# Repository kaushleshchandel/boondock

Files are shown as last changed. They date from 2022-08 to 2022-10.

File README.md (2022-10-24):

## Boondock Echo
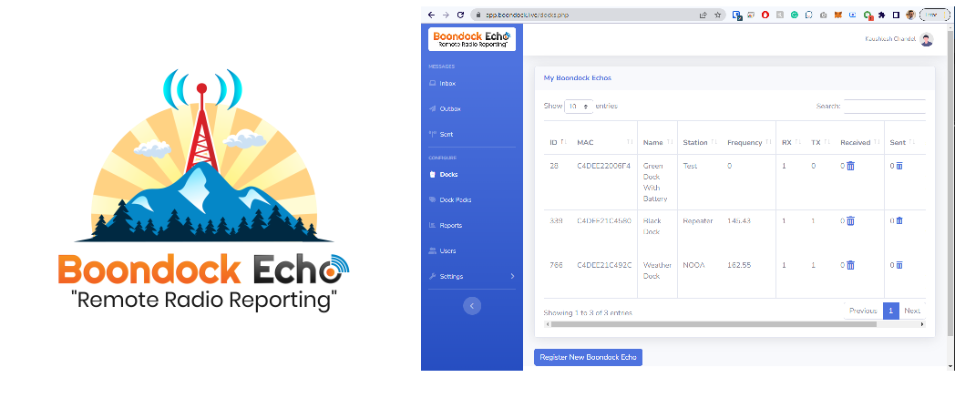
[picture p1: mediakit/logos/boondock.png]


### What is Boondock Echo?
Boondock Echo is a time-shift audio project created for emergency radio communications. A Boondock Echo module connects to transceivers with audio cables between the mic and speaker of the radio and the speaker and mic of the Bookdock Echo moule. 

The Boondock Echo listens to the radio for traffic. Whenever new traffic is received, it captures the audio as a .wav on a local sd card, and then sends the file to sever for storage, and queing, and playback. Users can play back messages on the Boondock browser interface or que messages for transmission on a radio.

Having the audio files on the cloud, enables us to have some really cool features to a radio, that were not possible earlier. like, converting audio to text, using text to speech, audio noice reduction, and pre-porcessing audio.

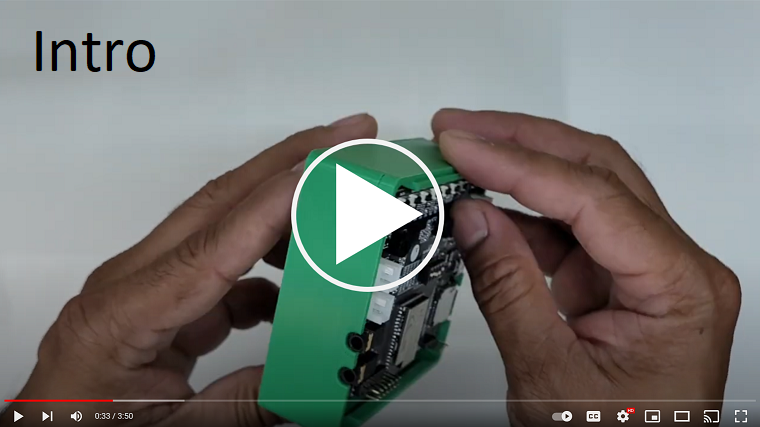
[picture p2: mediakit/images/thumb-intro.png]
Watch the video (https://youtu.be/K9tplKsggrA)
 

### How to get started with Boondock
All the source code you would need is included in this repositories. You will also need to create google cloud account for Text to Speech & Speech to Text features. The build instructions are split into four steps. Each part has a linked instructional video.

<ol>
  <li>Assembling the hardware</li>
  <li>Setting up the Web Server</li>
  <li>Programming the Boondock</li>
  <li>Getting Started</li>
</ol>

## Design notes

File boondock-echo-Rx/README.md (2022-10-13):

### STEP 3. Programming the Boondock

After assembling your boondock echo, you need a micro USB cable to program your boondock Echo. [CLICK HERE](/3d.print/README.md) for Assembly instructions and video.

#### Prepare the SD Card
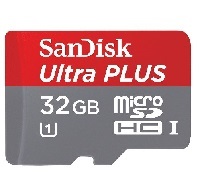
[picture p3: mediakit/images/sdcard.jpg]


You can use any size SD card and format it to FAT32. I have used a 32GB micro SD card, so I would recommend using the same.

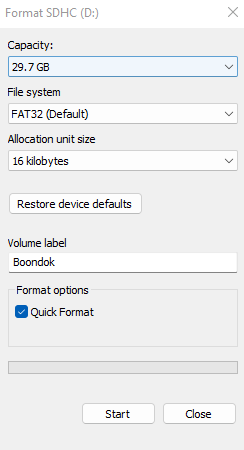
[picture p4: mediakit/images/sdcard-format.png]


After formatting the card, copy all the files from the folder named **sd_card**

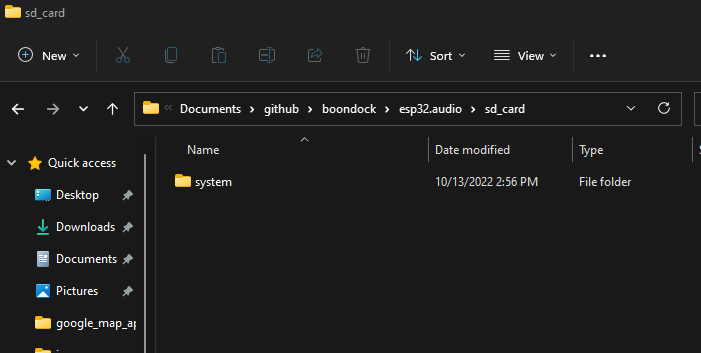
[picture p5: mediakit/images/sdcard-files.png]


The system folder has some files that are used by boondock Echo. After the boondock starts for the first time, it will create some folders. All the audio files are stored on the SD card.

#### Prepare the IDE to program Boondock Echo.

You can watch the detailed video on setting up Platform IO and Visual Studio code. If you are familiar with visual studio code, open the folder with ESP32 audio code.
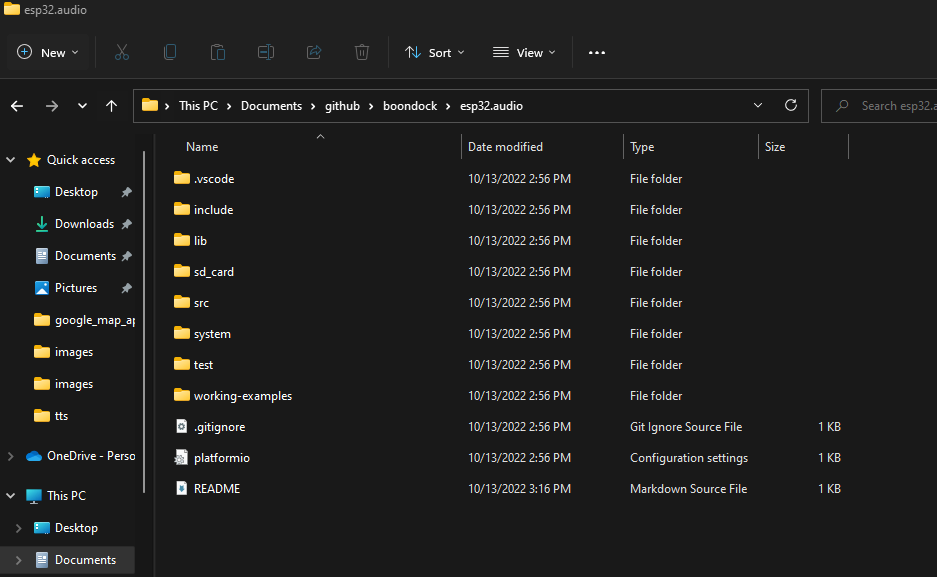
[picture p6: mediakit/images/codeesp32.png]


Before you upload the code, you need to setup some configurations.

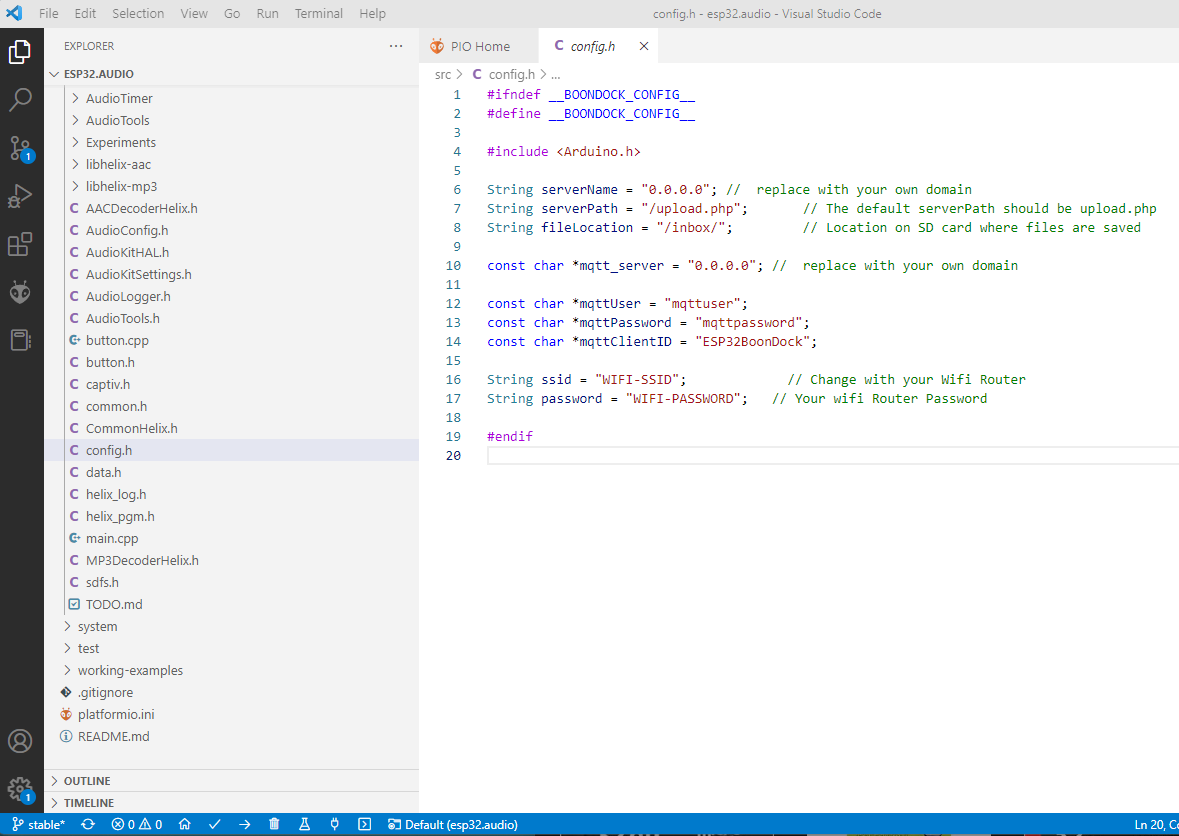
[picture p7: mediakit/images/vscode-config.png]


Now connect the Boondock Echo using a Micro USB cable, and click upload.
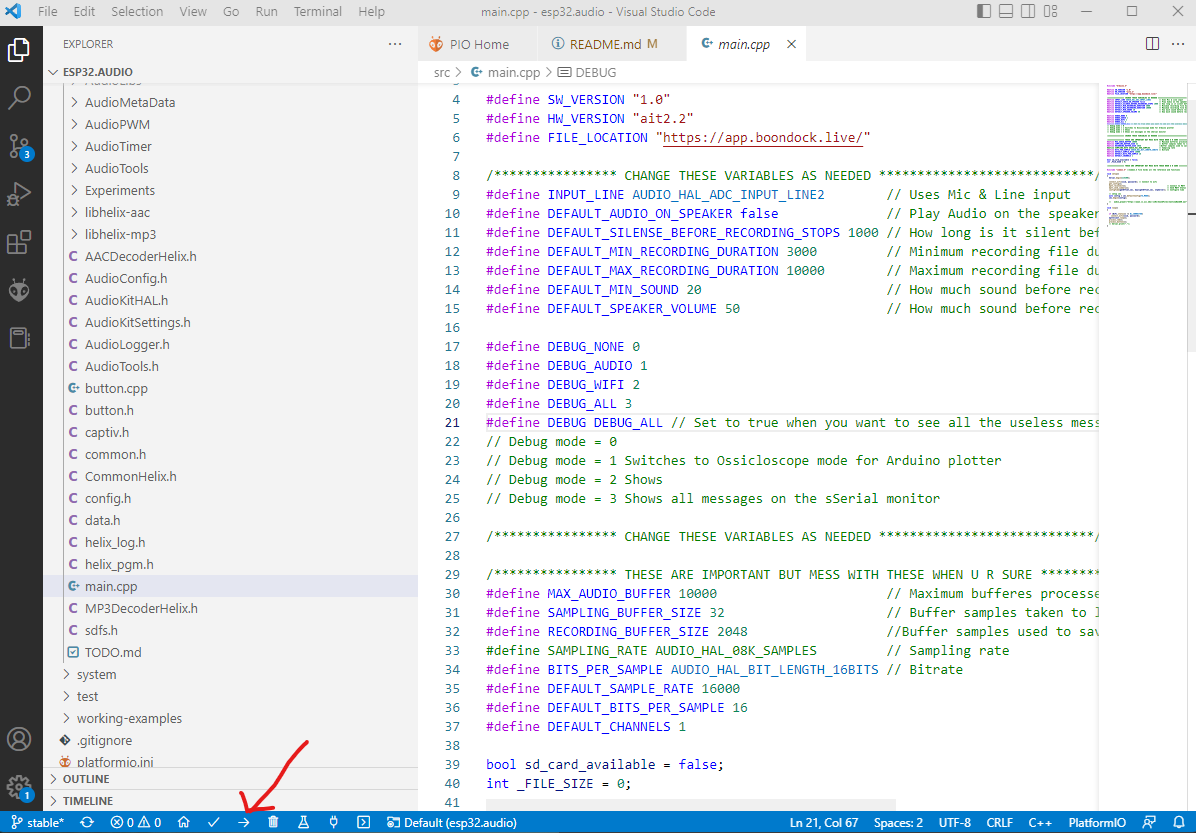
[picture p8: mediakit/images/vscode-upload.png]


Now your boondock echo is all set and ready for use.

**Cheers!**

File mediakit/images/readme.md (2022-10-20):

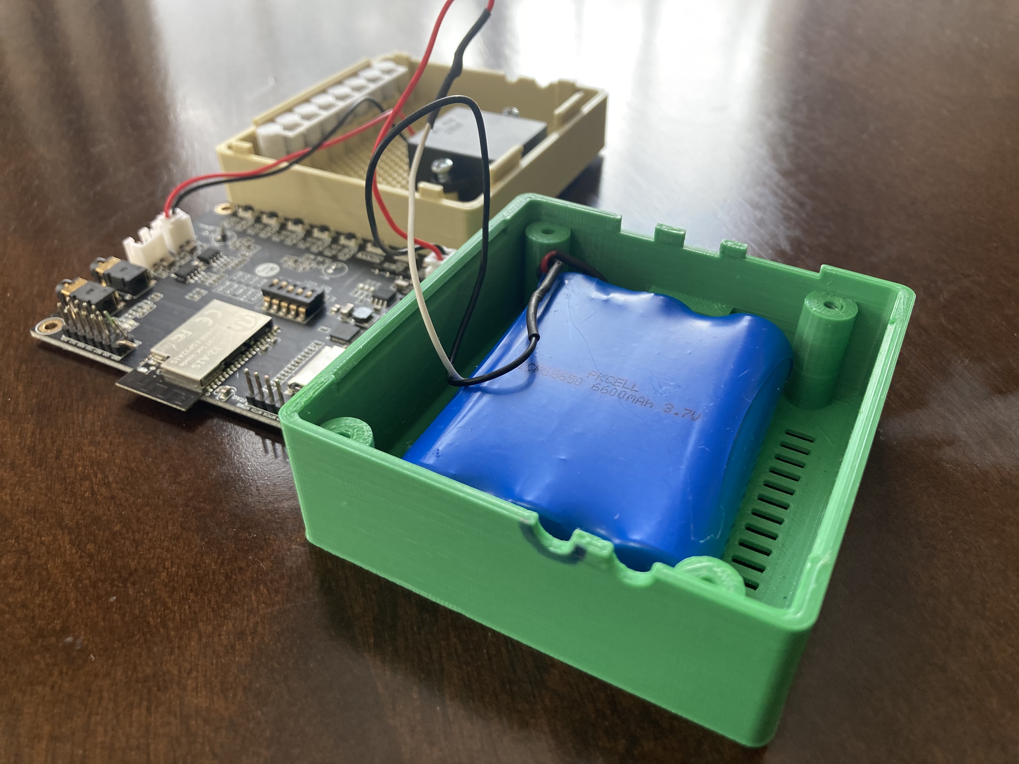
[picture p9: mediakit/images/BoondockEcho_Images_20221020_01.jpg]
Boondock Echo Open Case

 
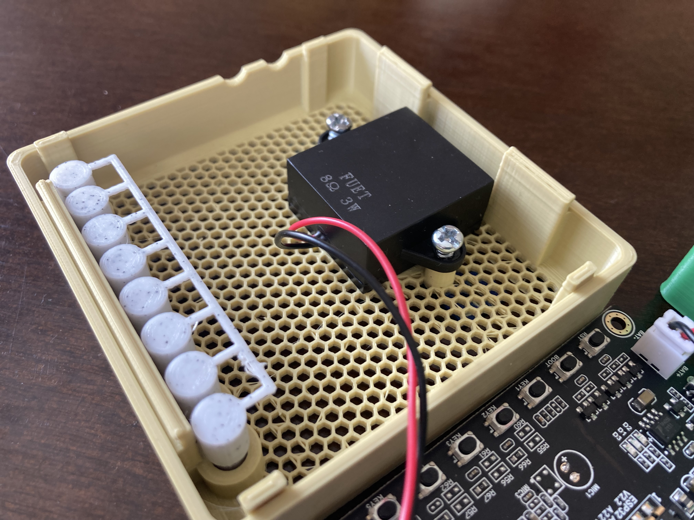
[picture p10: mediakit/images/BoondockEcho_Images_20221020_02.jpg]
Boondock Echo Top Case

 
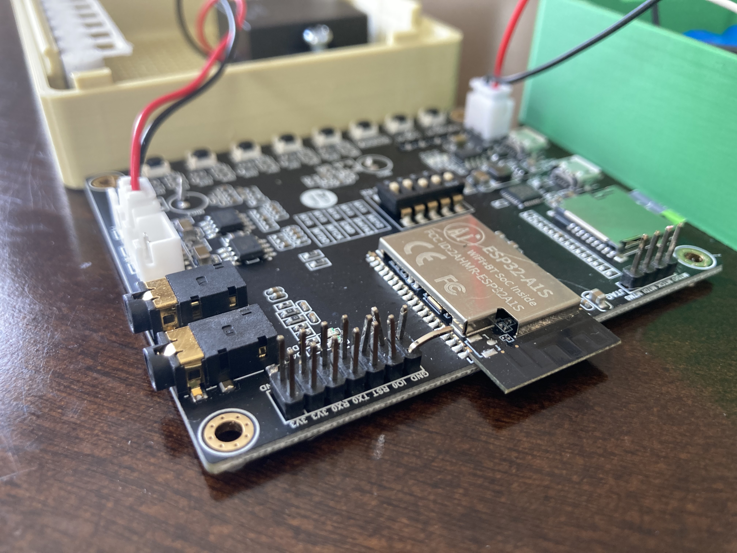
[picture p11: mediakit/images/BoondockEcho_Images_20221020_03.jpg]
Boondock Echo ESP Audio Kit

 
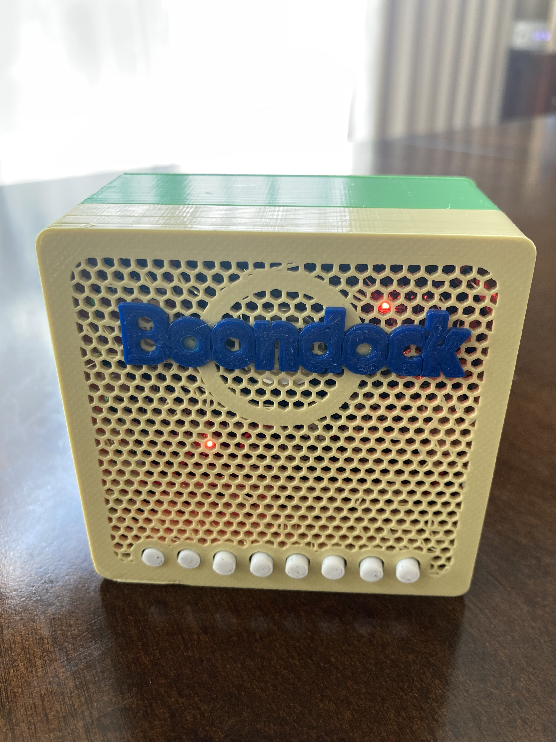
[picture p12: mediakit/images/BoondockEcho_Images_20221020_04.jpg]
Boondock Echo New Top Case Design

 
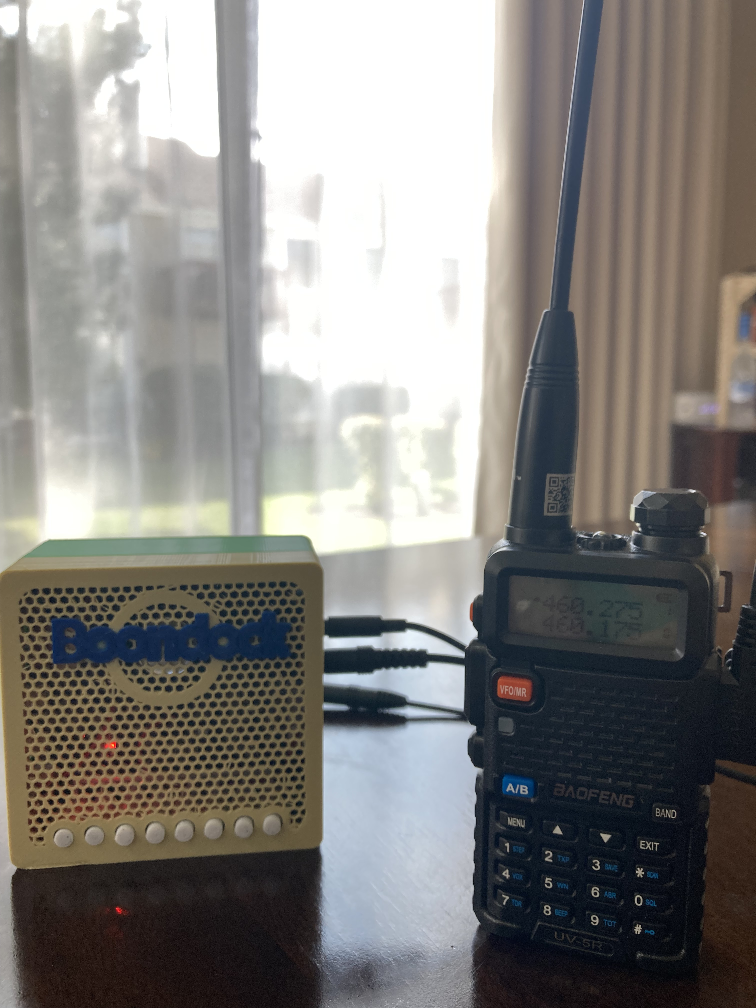
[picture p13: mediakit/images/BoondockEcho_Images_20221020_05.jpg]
Boondock Echo With Radio

 
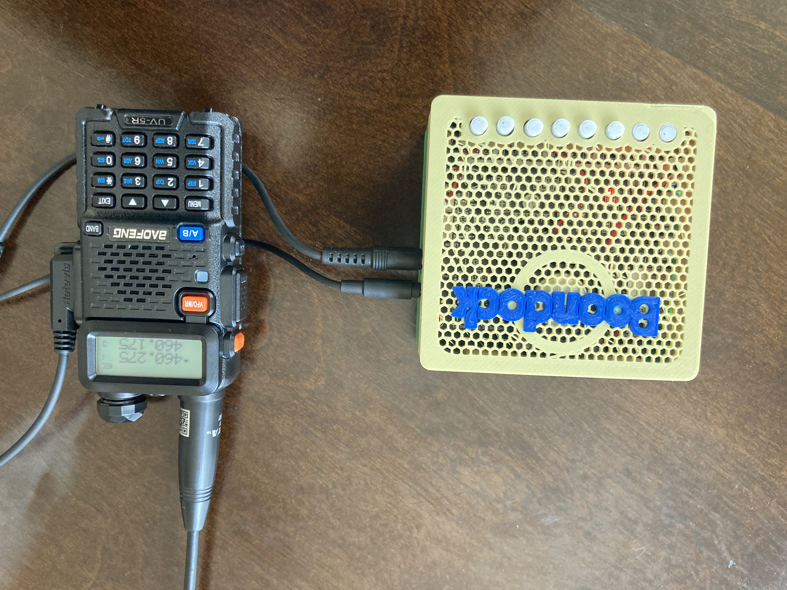
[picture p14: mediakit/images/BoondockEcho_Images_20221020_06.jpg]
Boondock Echo With Radio

 
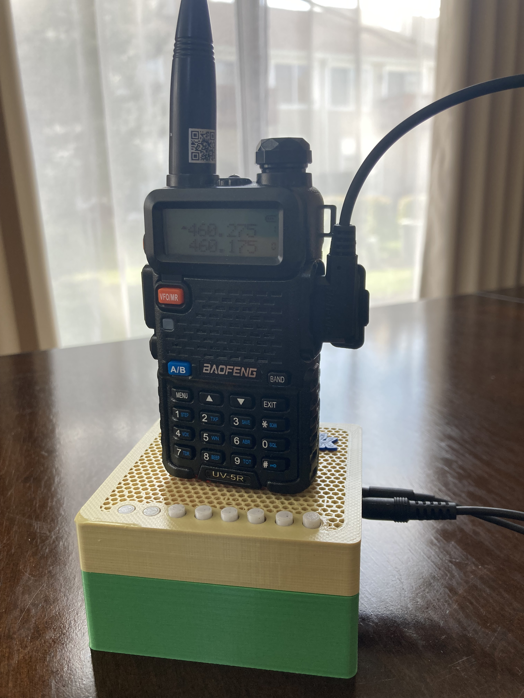
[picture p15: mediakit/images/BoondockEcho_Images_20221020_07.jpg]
Boondock Echo Under Radio

 
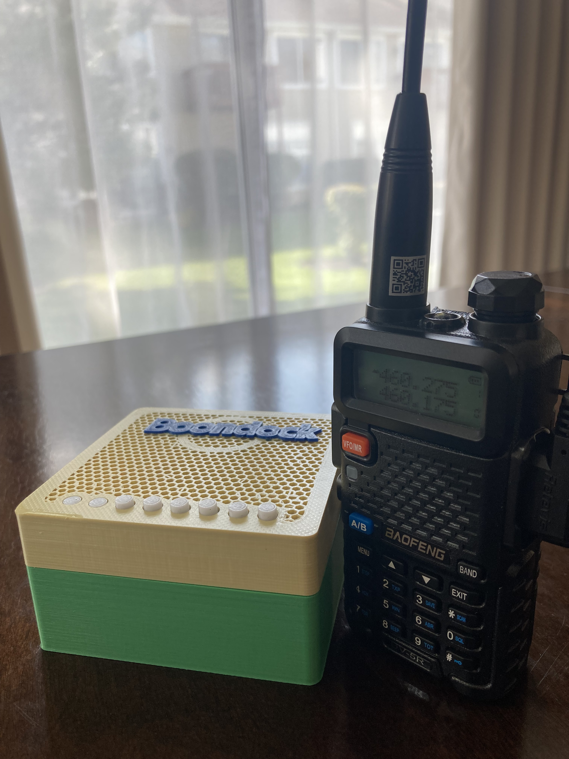
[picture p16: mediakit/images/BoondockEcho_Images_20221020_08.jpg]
Boondock Echo Next to Radio


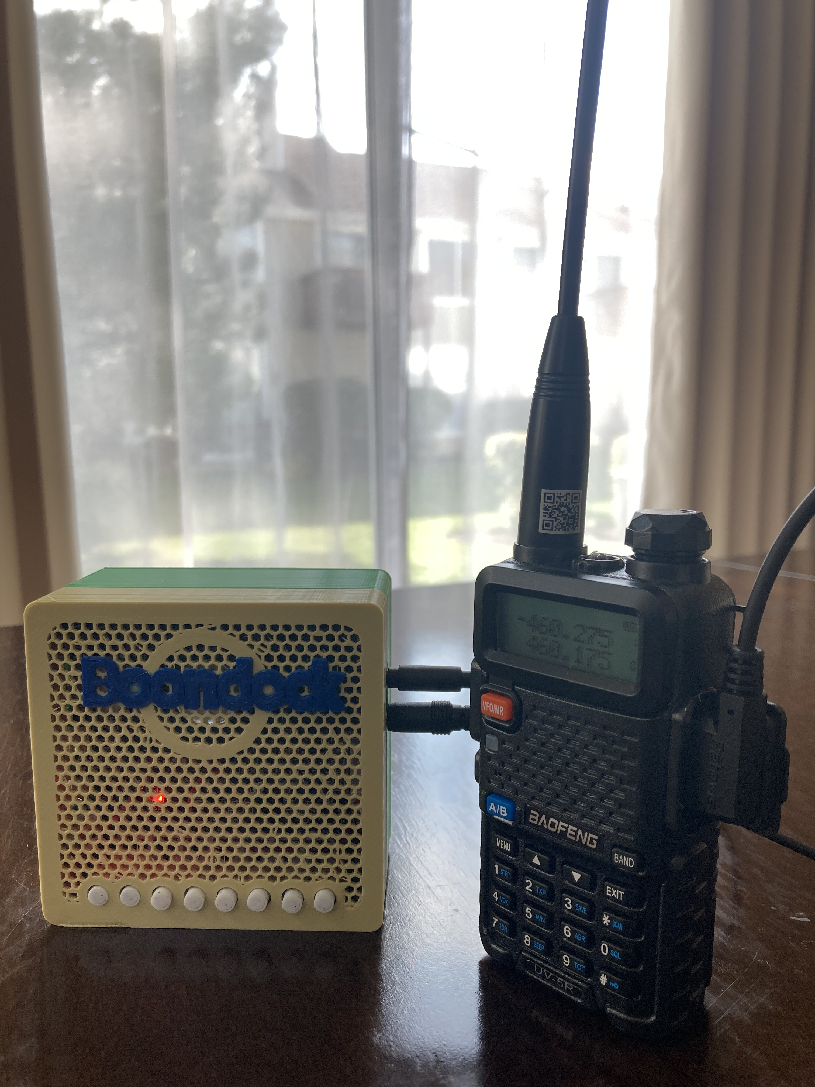
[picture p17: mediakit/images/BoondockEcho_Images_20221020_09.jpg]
Boondock Echo Next to Radio


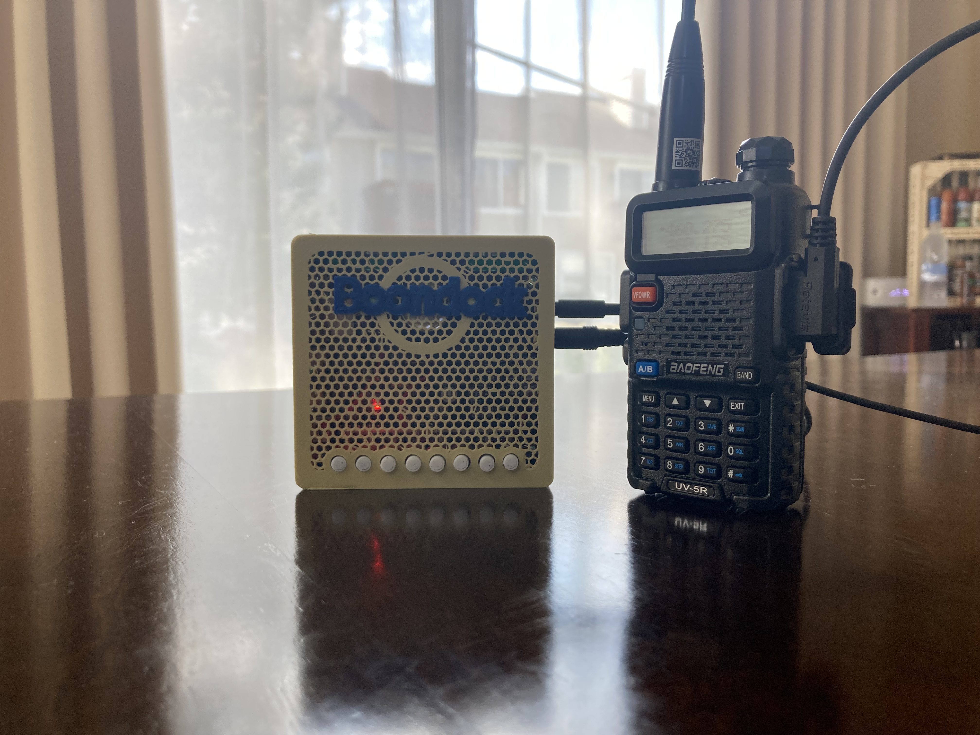
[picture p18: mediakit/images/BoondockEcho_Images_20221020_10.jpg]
Boondock Echo Next to Radio


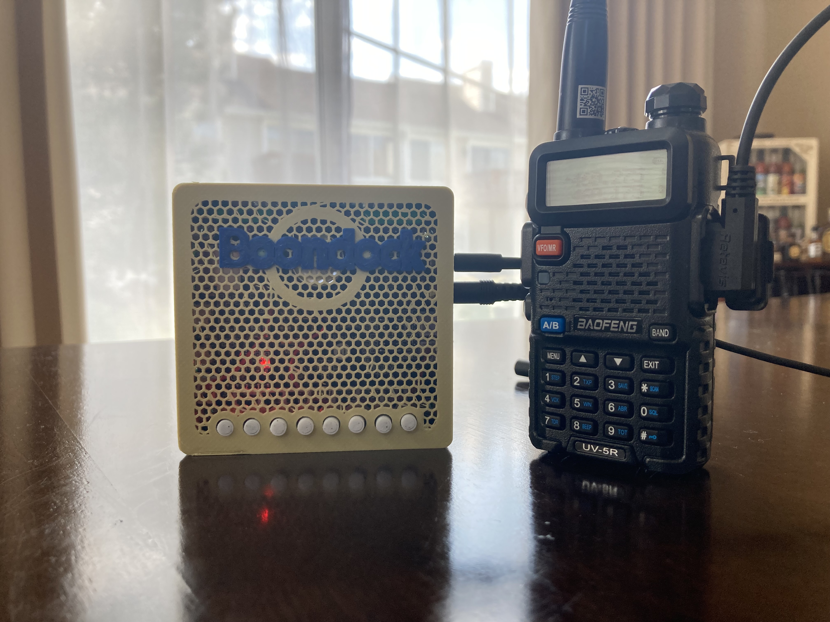
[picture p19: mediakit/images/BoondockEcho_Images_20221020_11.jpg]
Boondock Echo Next to Radio


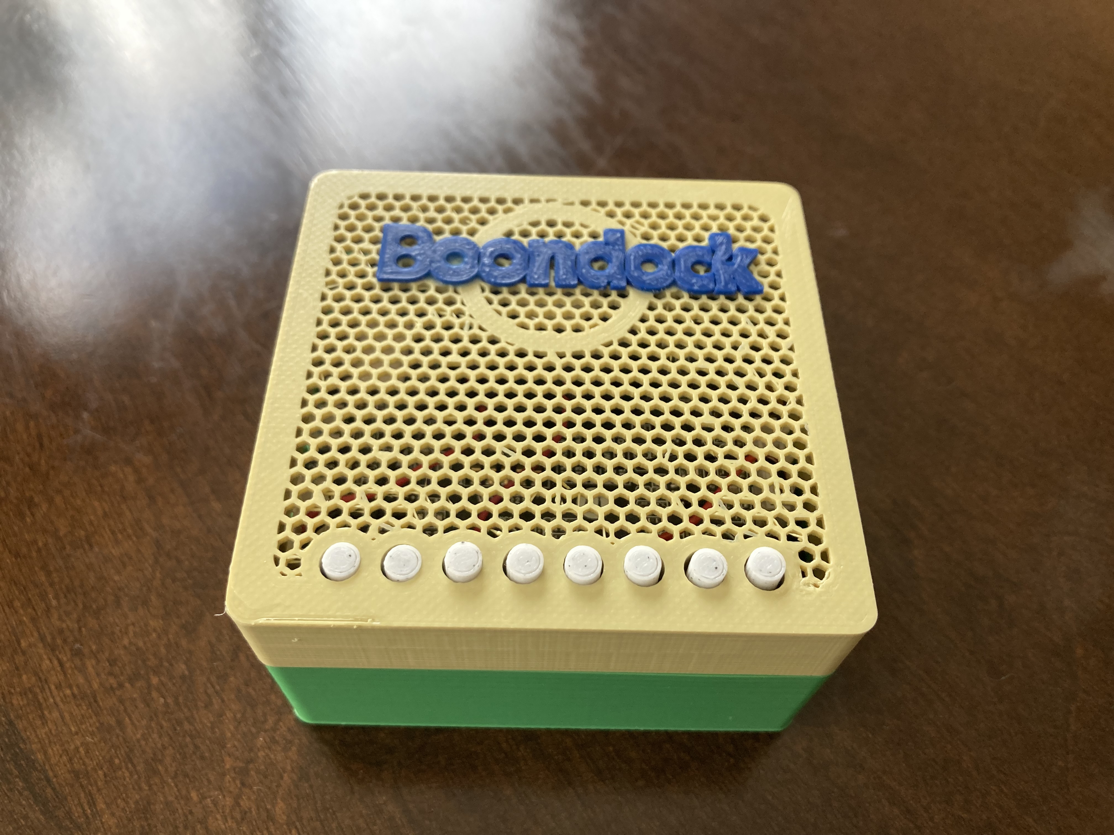
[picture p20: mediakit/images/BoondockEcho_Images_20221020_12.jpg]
Boondock Echo Next to Radio


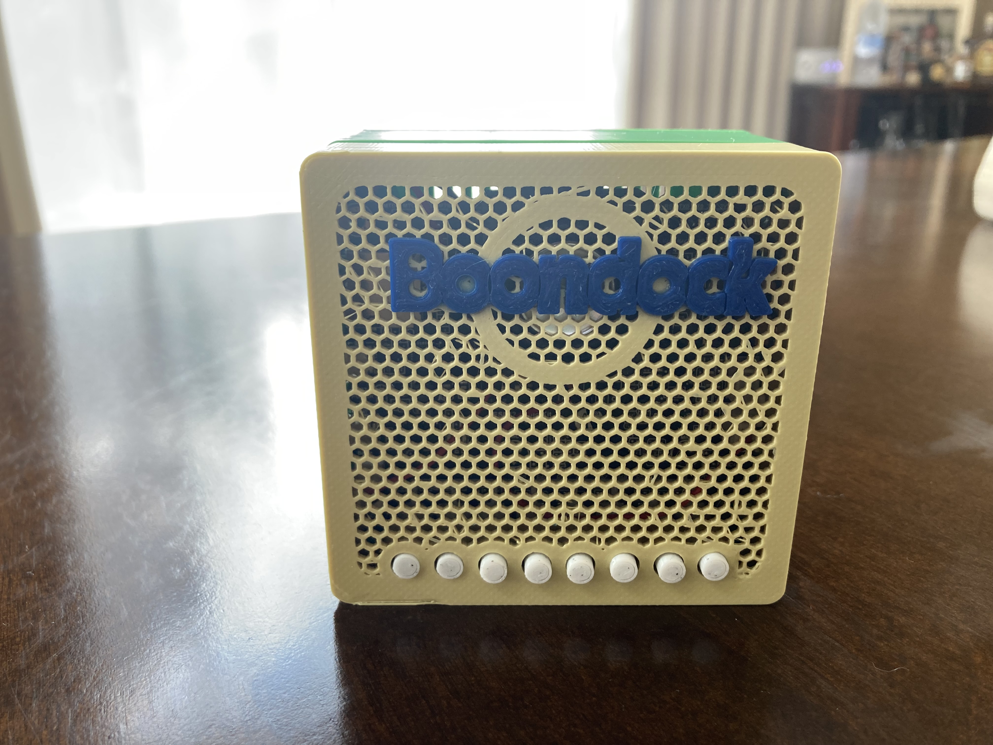
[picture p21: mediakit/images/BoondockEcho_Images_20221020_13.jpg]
Boondock Echo Next to Radio


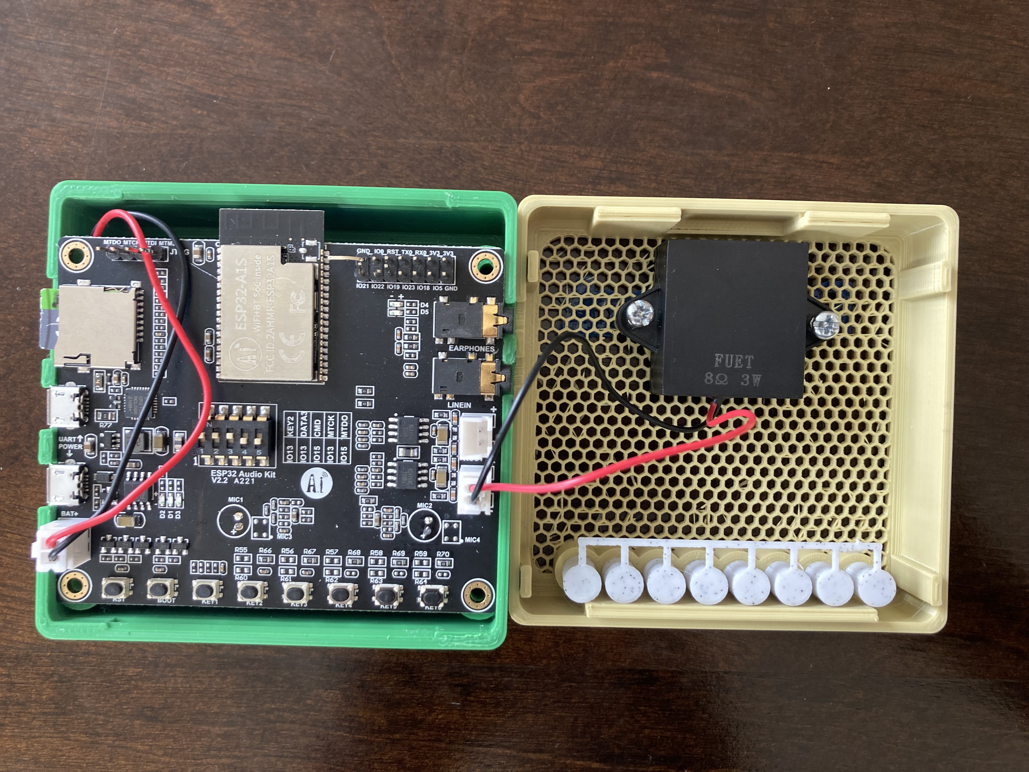
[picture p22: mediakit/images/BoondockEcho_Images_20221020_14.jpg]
Boondock Echo Next to Radio


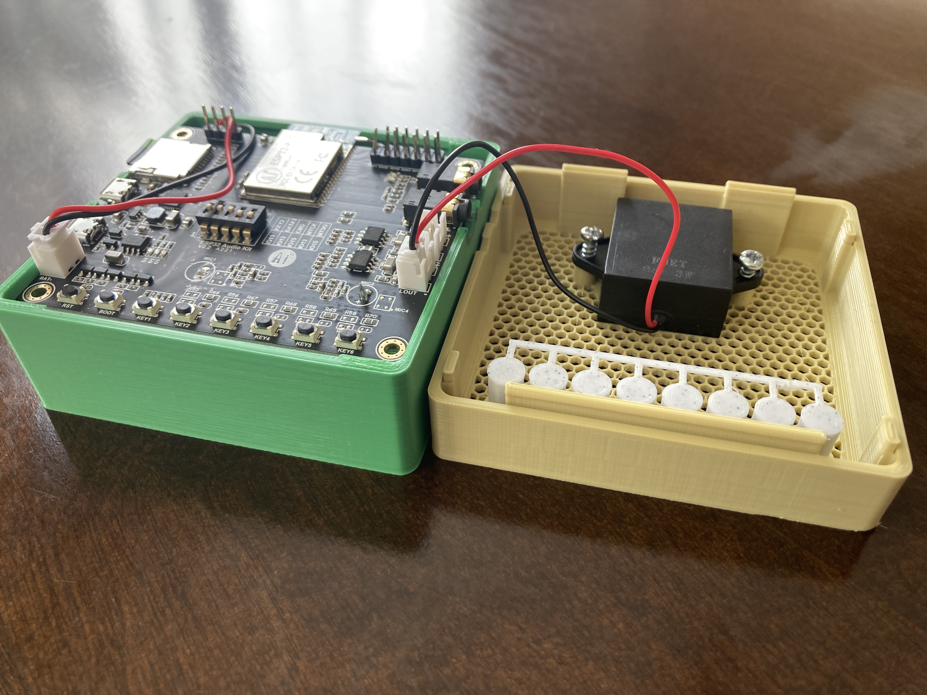
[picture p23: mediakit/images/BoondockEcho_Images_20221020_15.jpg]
Boondock Echo Next to Radio


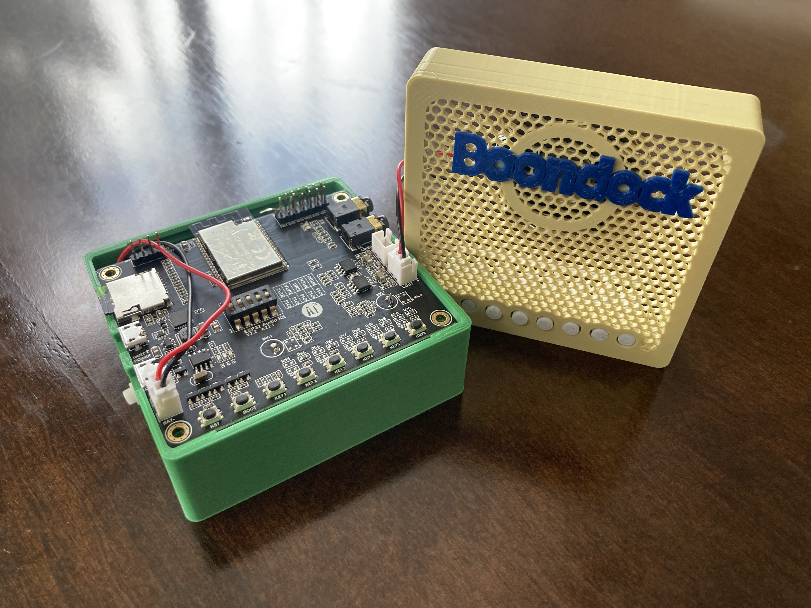
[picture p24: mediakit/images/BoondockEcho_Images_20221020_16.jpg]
Boondock Echo Next to Radio


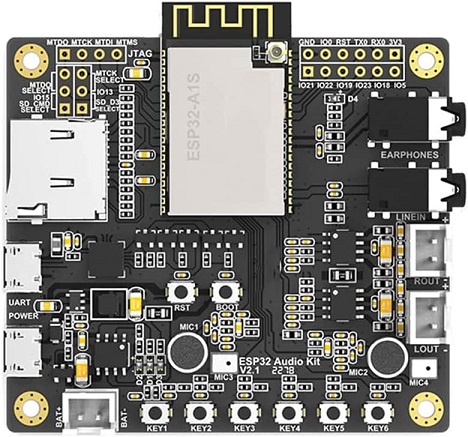
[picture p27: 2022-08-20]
web.server/images/esp32audio-1.jpg

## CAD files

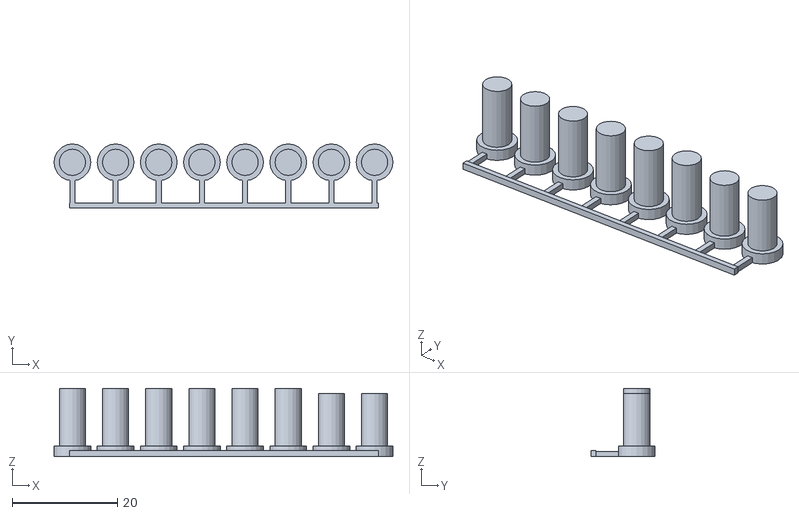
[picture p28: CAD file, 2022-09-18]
3d.print/Boondock_Slim_Buttons.stl
64.4 x 12.2 x 13.0

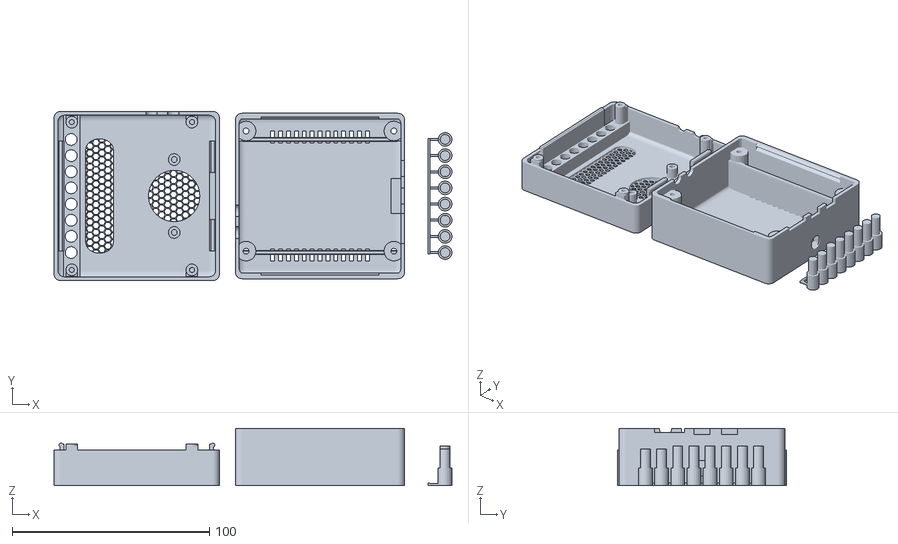
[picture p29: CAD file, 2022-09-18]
3d.print/Boondock_With_Battery_All_Parts.stl
202.0 x 86.0 x 29.0

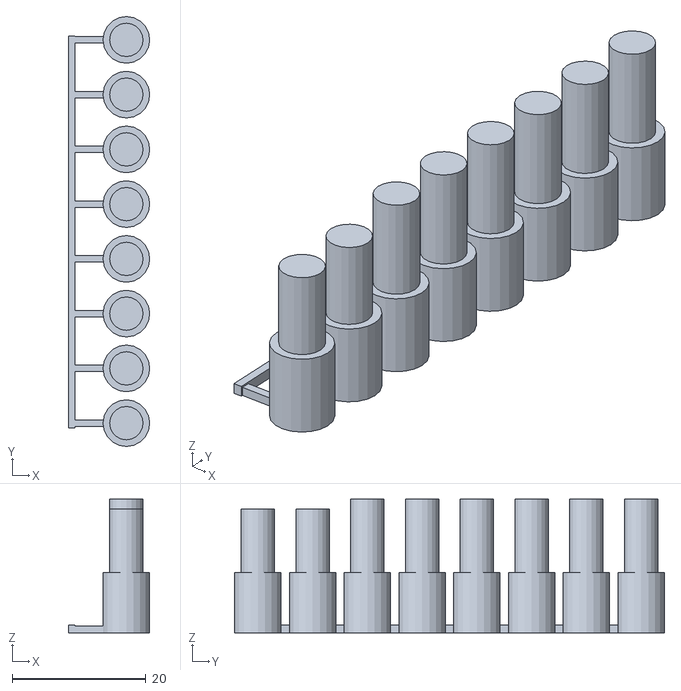
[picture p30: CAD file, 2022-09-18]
3d.print/Boondock_With_Battery_Buttons.stl
12.2 x 64.4 x 20.0

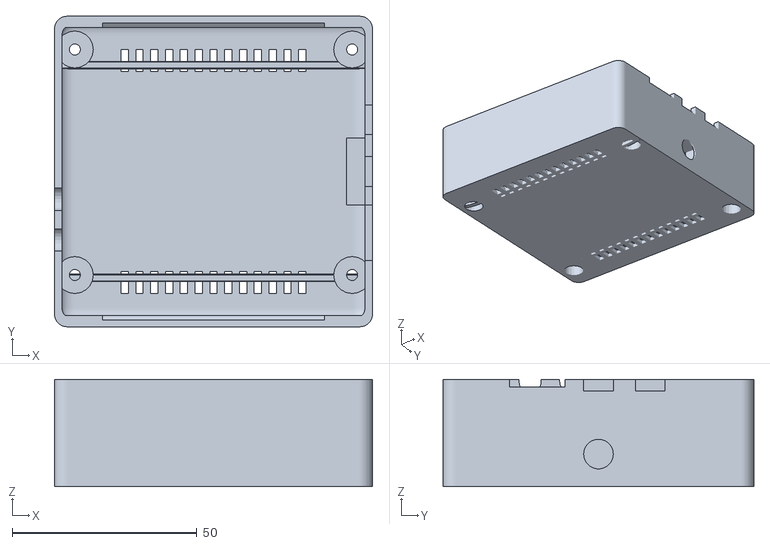
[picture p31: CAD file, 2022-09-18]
3d.print/Boondock_With_Battery_Bottom.stl
86.0 x 84.0 x 29.0

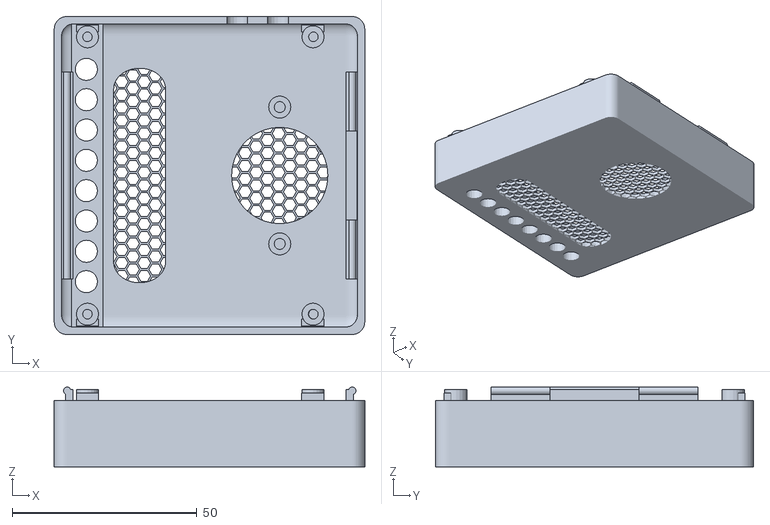
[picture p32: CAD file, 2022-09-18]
3d.print/Boondock_With_Battery_Top.stl
84.0 x 86.0 x 21.6

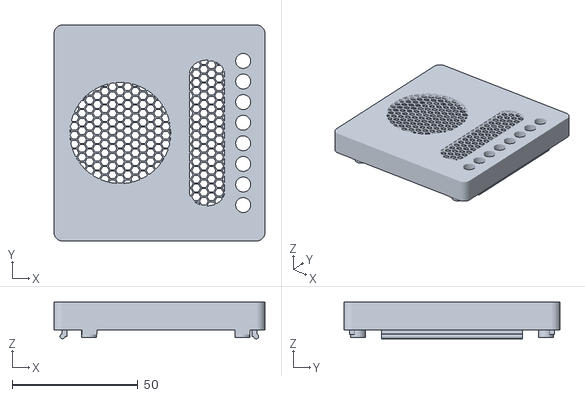
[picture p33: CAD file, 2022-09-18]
3d.print/Boondock_Slim_Top.stl
84.0 x 86.0 x 14.6

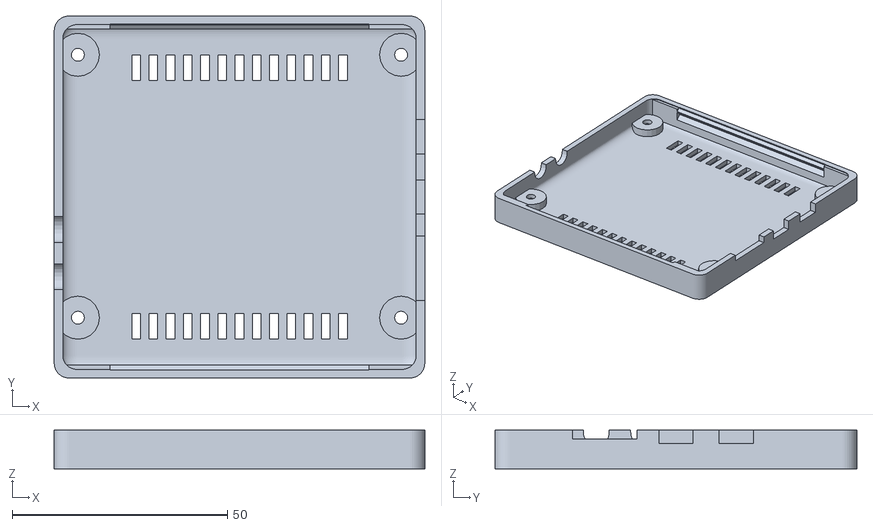
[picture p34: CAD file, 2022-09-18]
3d.print/Boondock_Slim_Bottom.stl
86.0 x 84.0 x 9.00

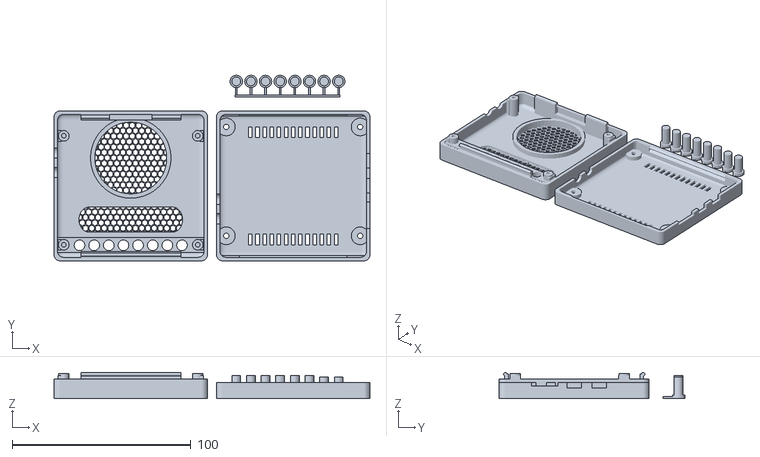
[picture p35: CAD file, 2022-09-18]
3d.print/Boondock_Slim_All_Parts.stl
177.0 x 104.0 x 14.6

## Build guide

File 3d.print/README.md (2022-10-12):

#3d Printing parts
 
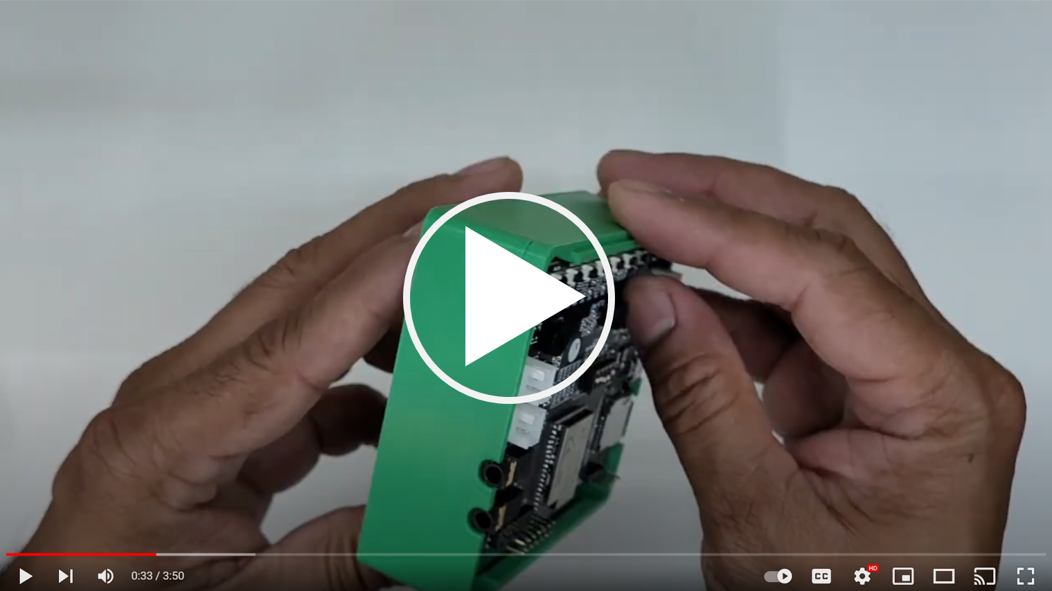
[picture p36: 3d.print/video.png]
Watch the video (https://youtu.be/K9tplKsggrA)
 

3d print the parts nesesary for Boondock Echo. 

## Boondock Echo with Battery

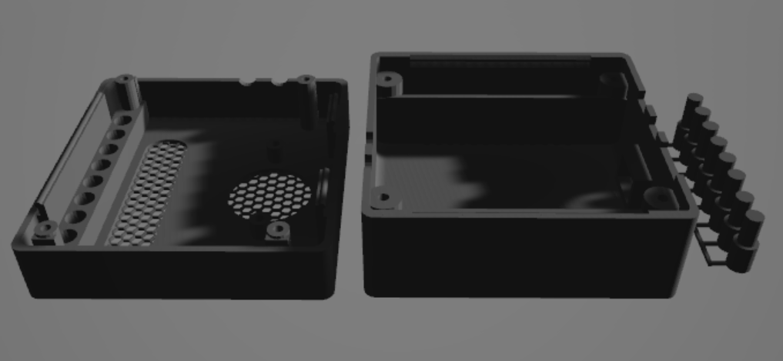
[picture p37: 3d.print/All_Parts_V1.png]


You can print one single file, or individual files for each part. Bondock Echo with battery holds a battery three cell Li-ion battery, a speaker, and a Pushbutton.

## Boondock Echo Slim

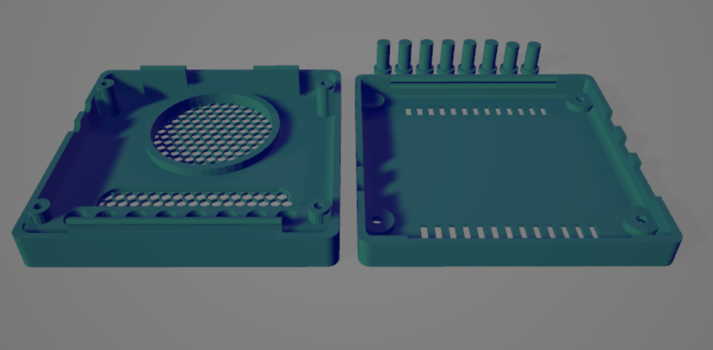
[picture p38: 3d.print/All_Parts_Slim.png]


Boondock Slim can be installed with or without a thin profile speaker. It doesnt have a power on/off button. You can power the device with a micro USB cable.

### Links to all the parts

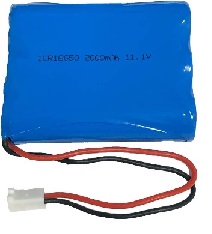
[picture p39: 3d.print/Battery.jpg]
Battery

[Amazon link to battery](https://a.co/d/b0EKAVF)

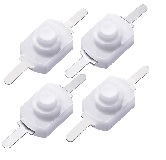
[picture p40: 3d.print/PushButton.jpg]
Pushbuttons

[Amazon link to push buttons](https://a.co/d/g9sqHGD)
 
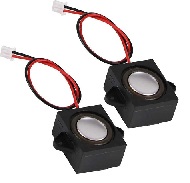
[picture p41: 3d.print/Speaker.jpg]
Speaker

[Amazon link to Speakers](https://a.co/d/degUwFO)

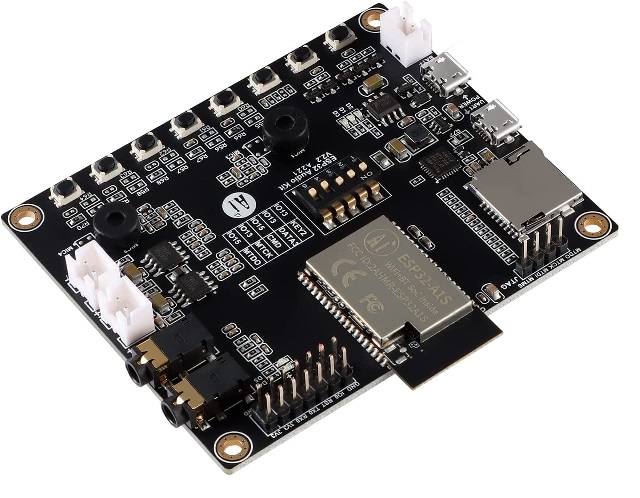
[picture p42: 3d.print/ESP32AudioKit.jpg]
ESP32

[Amazon link to ESP32 Audio Kit](https://a.co/d/4O83x4C)

[Amazon link to Baofeng Radio](https://a.co/d/3xN6RiG)

[Amazon link to Audio Cable](https://a.co/d/8nfM7wO)

To build Boondock, you need ESP32 Audio kit, a speaker, Li-ion battery, a power switch, and a 3d printed enclosure with some screws. 

List of purchasable components.
Currently supported module:
<ol>
  <li>1x ESP32 Based Audio Interface: https://www.amazon.com/gp/product/B0B63KZ6C1 </li>
</ol>

The following parts are what we used to make the prototype.  Other substitutes are fine:
<ol>
  <li>1x Handie-Talkie: (Baofeng UV-5R: https://www.amazon.com/dp/B074XPB313 or similar)</li>
  <li>1x 3.7V rechargable battery with 2.0 mm 2 pin JST connector: (https://www.amazon.com/dp/B095DQJ69Q or simlar)</li>
  <li>2x 3.5mm male audio cable (https://www.amazon.com/dp/B076BFZDG2/ or similar)</li>
  <li>1x 3.5mm female to 2.5 mm male stereo audio jack: (https://www.amazon.com/dp/B01FPRADYK or similar)</li>
  <li>1x Speaker with 2.0mm 2 pin JST connector (https://www.amazon.com/dp/B07FTB281F or similar)</li>
</ol>

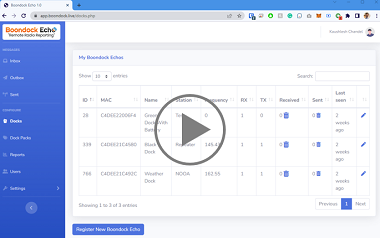
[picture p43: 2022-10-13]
mediakit/images/thumb-getting-started.png

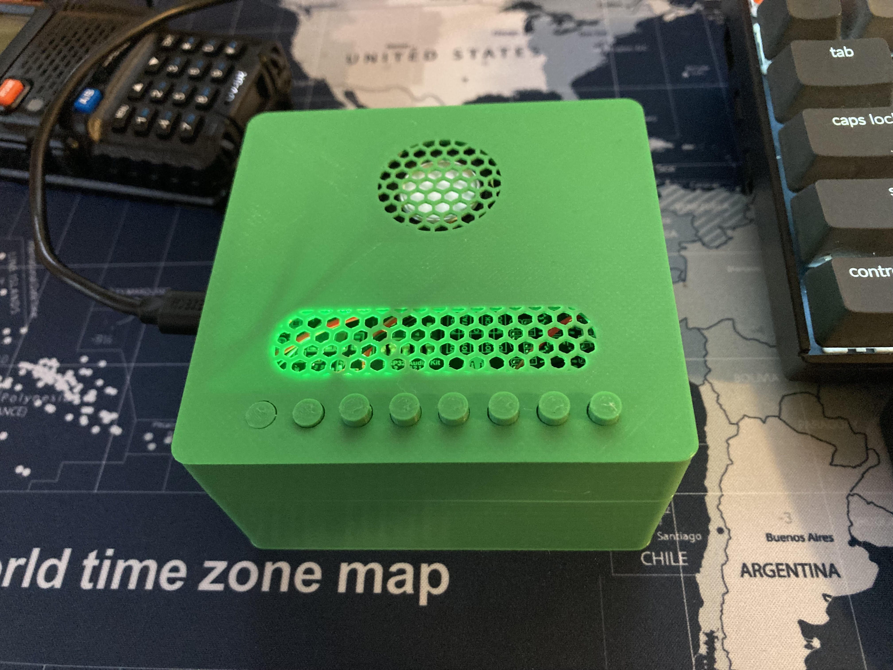
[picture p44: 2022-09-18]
3d.print/BoondockEcho.jpg

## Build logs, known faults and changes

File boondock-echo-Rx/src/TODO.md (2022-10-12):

 # TODO

•   Server Side - Identify & test a boondock
•	WiFi Manager
•	6 letter Code on WiFi Manager
•	Web interface to Add & Remove the Device

 - Fetch settings from the server on begin
 - Update when there is a change to the settings
 - Push to Record ( Sends audio to Server ) 
 - Say the Status on button press
 - Mirror the Audio in to Speaker out
 - Button Press to switch the Microphone Input

 - Cycle oldest Audio file
 - Button Press to Clean up storage
 - Add all buttons and their functions.
 - Record on demand on button press.
 - SERVER SIDE - Accept audio files, save to database.

 - Fix the Audio sampling rate
 - Detect Mic & Speakers conencted
 - Async sending file to server

 - Add MQTT commands
 - Button Press commands to enable & disable recording

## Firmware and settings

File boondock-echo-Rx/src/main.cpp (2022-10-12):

#include "Arduino.h"

#define SW_VERSION "1.0"
#define HW_VERSION "ait2.2"
#define FILE_LOCATION "https://app.boondock.live/"

/**************** CHANGE THESE VARIABLES AS NEEDED ****************************/
#define INPUT_LINE AUDIO_HAL_ADC_INPUT_LINE2        // Uses Mic & Line input
#define DEFAULT_AUDIO_ON_SPEAKER false              // Play Audio on the speaker?
#define DEFAULT_SILENSE_BEFORE_RECORDING_STOPS 1000 // How long is it silent before recording stops; in milliseconds
#define DEFAULT_MIN_RECORDING_DURATION 3000         // Minimum recording file duration; in Milliseconds
#define DEFAULT_MAX_RECORDING_DURATION 10000        // Maximum recording file duration; in Milliseconds
#define DEFAULT_MIN_SOUND 20                        // How much sound before recording starts Range 0 to 100;
#define DEFAULT_SPEAKER_VOLUME 50                   // How much sound before recording starts Range 0 to 100;

#define DEBUG_NONE 0
#define DEBUG_AUDIO 1
#define DEBUG_WIFI 2
#define DEBUG_ALL 3
#define DEBUG DEBUG_ALL // Set to true when you want to see all the useless messages scrolling on serial port
// Debug mode = 0
// Debug mode = 1 Switches to Ossicloscope mode for Arduino plotter
// Debug mode = 2 Shows
// Debug mode = 3 Shows all messages on the sSerial monitor

/**************** CHANGE THESE VARIABLES AS NEEDED ****************************/

/**************** THESE ARE IMPORTANT BUT MESS WITH THESE WHEN U R SURE *********/
#define MAX_AUDIO_BUFFER 10000                      // Maximum bufferes processed before recording is stopped
#define SAMPLING_BUFFER_SIZE 32                     // Buffer samples taken to listen for sound activity
#define RECORDING_BUFFER_SIZE 2048                  //Buffer samples used to save the audio file\
#define SAMPLING_RATE AUDIO_HAL_08K_SAMPLES         // Sampling rate
#define BITS_PER_SAMPLE AUDIO_HAL_BIT_LENGTH_16BITS // Bitrate
#define DEFAULT_SAMPLE_RATE 16000
#define DEFAULT_BITS_PER_SAMPLE 16
#define DEFAULT_CHANNELS 1

bool sd_card_available = false;
int _FILE_SIZE = 0;

/**************** THESE ARE IMPORTANT BUT MESS WITH THESE WHEN U R SURE *********/

#include "common.h" //Common.h file holds all the reference and functions

void setup()
{
  Serial.begin(115200);

  connect_wifi(ssid, password); // Connect to wifi
  get_config();
  mqtt_reconnect();                                         // Connect to MQTT
  mqtt_send_summary();                                      // Send MQTT Status & Config data
  configTime(gmtOffset_sec, daylightOffset_sec, ntpServer); // Configure time

  // setup i2s
  auto config = i2s.defaultConfig(TX_MODE);
  i2s.begin(config);

  //   audio_player("https://www2.cs.uic.edu/~i101/SoundFiles/CantinaBand60.wav");
}

void loop()
{

  if (WiFi.status() != WL_CONNECTED)
    connect_wifi(ssid, password);
  mqttClient.loop();
  process_led();
  process_buttons();
  // Serial.print(".");
}

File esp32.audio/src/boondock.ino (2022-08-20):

/**
 * @file streams-url_mp3-audiokit.ino
 * @author Phil Schatzmann
 * @brief decode MP3 stream from url and output it on I2S on audiokit
 * @version 0.1
 * @date 2021-96-25
 * 
 * @copyright Copyright (c) 2021
 */

// install https://github.com/pschatzmann/arduino-libhelix.git

#include "AudioTools.h"
#include "AudioCodecs/CodecMP3Helix.h"
#include "AudioLibs/AudioKit.h"


URLStream url("AAA","608980608980");  // or replace with ICYStream to get metadata
AudioKitStream i2s; // final output of decoded stream
EncodedAudioStream dec(&i2s, new MP3DecoderHelix()); // Decoding stream
StreamCopy copier(dec, url); // copy url to decoder


void setup(){
  Serial.begin(115200);
  AudioLogger::instance().begin(Serial, AudioLogger::Info);  

  // setup i2s
  auto config = i2s.defaultConfig(TX_MODE);
  i2s.begin(config);

  // setup I2S based on sampling rate provided by decoder
  dec.begin();

  // mp3 radio
  url.begin("http://events.bluevan.io/boondock/audio/welcome.mp3","audio/mp3");

}

void loop(){
  copier.copy();
}

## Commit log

2022-08-20 Added stl files
    [Bottom.stl, Buttons.stl, Top.stl]
2022-08-20 Updated esp32 image
2022-08-20 Updated top and buttons stl
    [Buttons.stl, Top.stl]
2022-08-20 Added Base Code for ESP32 Audio module
2022-09-04 Added sample code to capture audio
2022-09-08 Checkin added sample mp3 files
2022-09-13 Check with updated server and fixed bitrate
    [main.cpp]
2022-09-18 Checkin for 3d print
    [Boondock_Slim_All_Parts.stl, Boondock_Slim_Bottom.stl, Boondock_Slim_Buttons.stl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]
